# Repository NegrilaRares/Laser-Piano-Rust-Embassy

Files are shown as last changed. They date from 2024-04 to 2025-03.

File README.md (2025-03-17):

# Laser Piano
A piano made using laser diodes and laser receivers.

:::info 

**Author**: Negrila Rares \
**GitHub Project Link**: https://github.com/UPB-FILS-MA/project-NegrilaRares

:::

## Description

A piano made using laser diodes and laser receivers.

It uses a potentiometer with leds to adjust and show volume, 
3 separete switches with leds to displat change in octave 
and 7 laser diodes and laser receivers that act as the piano keys.

The plan is to take the sound data from an sd card and give it to a dac that will give the analog output to a audio jack module the is connected to a portable speaker.
It uses an LM386 audio amplifier module and 2 RC low pass filters to keep the signal clear and to a reasonable level.

## Motivation

The reason I chose this project is because I took an interest in laser diodes 
and wanted to learn file reading/writing from an external memory device 
as well as understand the conversion of digital code into analog sound.

## Architecture 

<!-- Add here the schematics with the architecture of your project. Make sure to include:
 - what are the main components (architecture components, not hardware components)
 - how they connect with each other
 -->

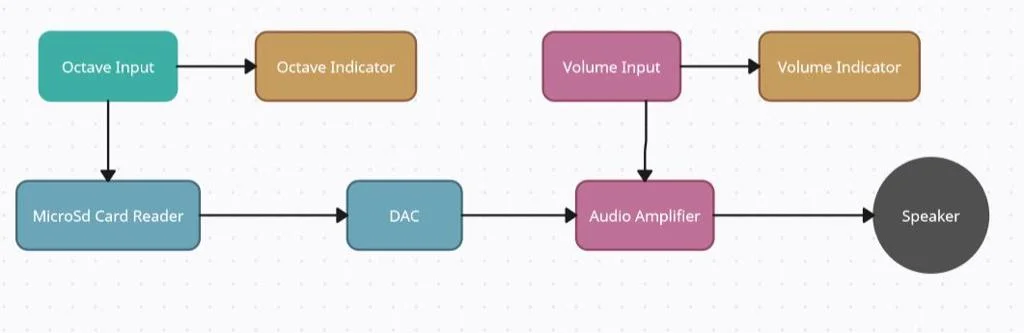
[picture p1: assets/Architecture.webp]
architecture
 

## Log

<!-- write every week your progress here -->

### Week 6 - 12 May

I encountered many problems with SD / microSD cards in embassy-rs.

While the setup initially used matched the Raspberry Pi Pico embedded-hal example from rp-rs using the embedded-sdmmc-rs crate, it did not behave as expected. The SD card itself failed to be read in any way, shape, or form. Even when manually sending CMD0, CMD1, and CMD8 commands, the response was not within the expected parameters.

In the end, I found a solution. I created a blocking::spi::SpiDevice using embassy_embedded_hal. 

For initialization, I had to give the program ownership over a phantom CS pin—a CS pin that could not be used and would no longer need to be used in the case of microSDs.

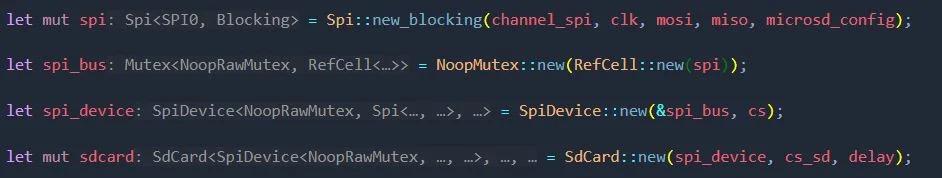
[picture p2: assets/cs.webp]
code_1


I opted for a normal SD card in the end, where I could still connect the second CS pin, given that the SD card module comes with 2 rows of pins.

### Week 7 - 19 May

After getting the SD card reader to work, I encountered my next challenge: data processing and the RAM limitations of the Raspberry Pi Pico.

Since the files themselves did not have too large of a PCM, storing them temporarily was not an issue. However, giving the data to the DAC proved to be a challenge.

For some reason, the while loop I was creating for processing did not accept any awaits or it would panic almost instantly. Additionally, giving the microcontroller too much to work on in too many iterations proved to be impossible.

To address this, I had to cut the files from 16-bit WAV files to 8-bit. This made processing much easier because now I only had to give an empty byte (with the first 4 bits setting the fast write mode of the DAC and the last 4 bits being empty data for the 12-bit interface) and the data bytes taken from the SD card. With this approach, I managed to cut the iterations from approximately 57,600 to about 28,650, and data processing to about 25%.

Despite these optimizations, the processing speed still proves to be insufficient. I see little solution to apply within my current limitations.

The biggest downside of using 8-bit files is that the sound quality took a significant plunge.

Now that I had my sound working, I needed to start working on clearing it up, as it was, at that time, an unintelligible mess.

To improve the sound quality, I switched to a portable speaker rather than the one I used before, and I attached an audio jack module to connect it. This proved to be insufficient, so I employed some RC low-pass filters to make some final touches.

While now there is still some static, it is nowhere near as bad as before. 
Despite the 8-bit sound quality, the sound can now be differentiated between keys.

### Week 20 - 26 May

The project ended up working perfectly on the breadboards as a prototype.

Sadly after putting the final version together, soldering everything on some prototype pcbs and putting everything in a wooden casing, I have lost a lot of the sound quality due to interference from the solder of the pcb.

Everything still functions ok.

The sound leaves a bit more to be desired when compared to the breadboard version.

This has been a lesson to me about analog waves and soldering, without experience, they don't go well together.

## Hardware

Using LEDs as settings indicators, buttons and a stereo potentiometer for octave and volume respectively.

Seven laser diodes are placed at an angle to continuously shine on the laser receivers.

An SD card reader is used with a 16GB SD card (the card has to use the W95 FAT32 (LBA) format). 

A DAC is used for processing the data and an amplifier is used to keep the signal at a desirable level.

Two RC low-pass filters are employed, each with 1780 kΩ resistors.

One filter uses a 0.1 µF capacitor, while the other uses a 0.22 µF capacitor.

The amplifier is connected to the opposite port of the stereo potentiometer, and the speaker is connected to the output of the amplifier through an audio jack module.

Full breadboard prototype:

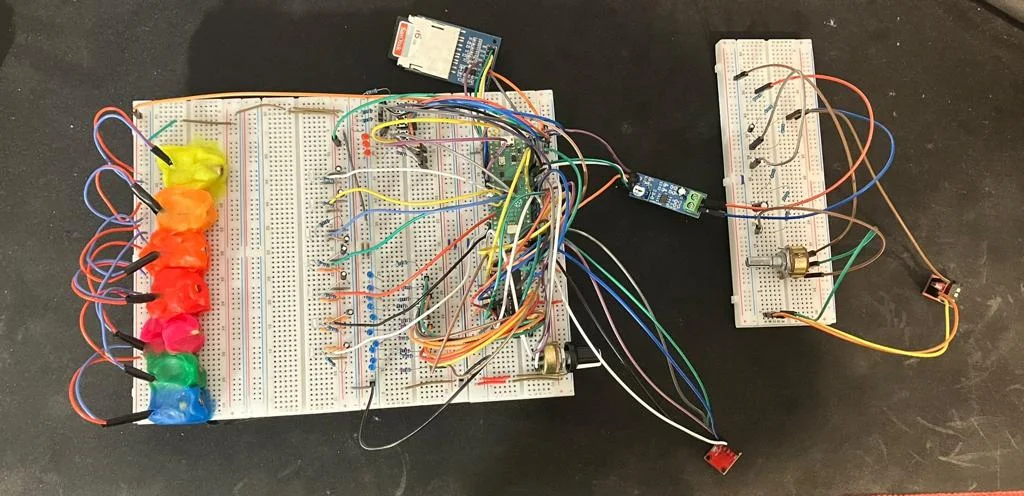
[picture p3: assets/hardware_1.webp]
hardware_on_breadboard


Laser processing:

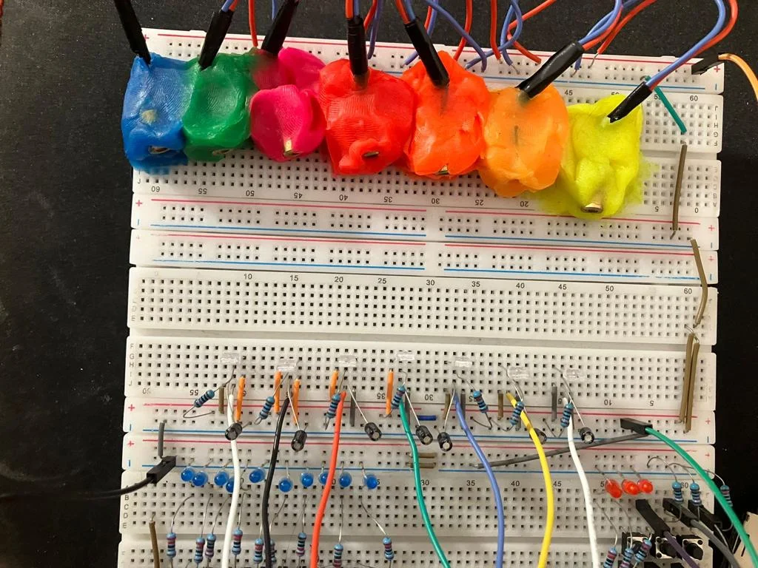
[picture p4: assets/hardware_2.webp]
hardware_on_breadboard


Analog signal processing:

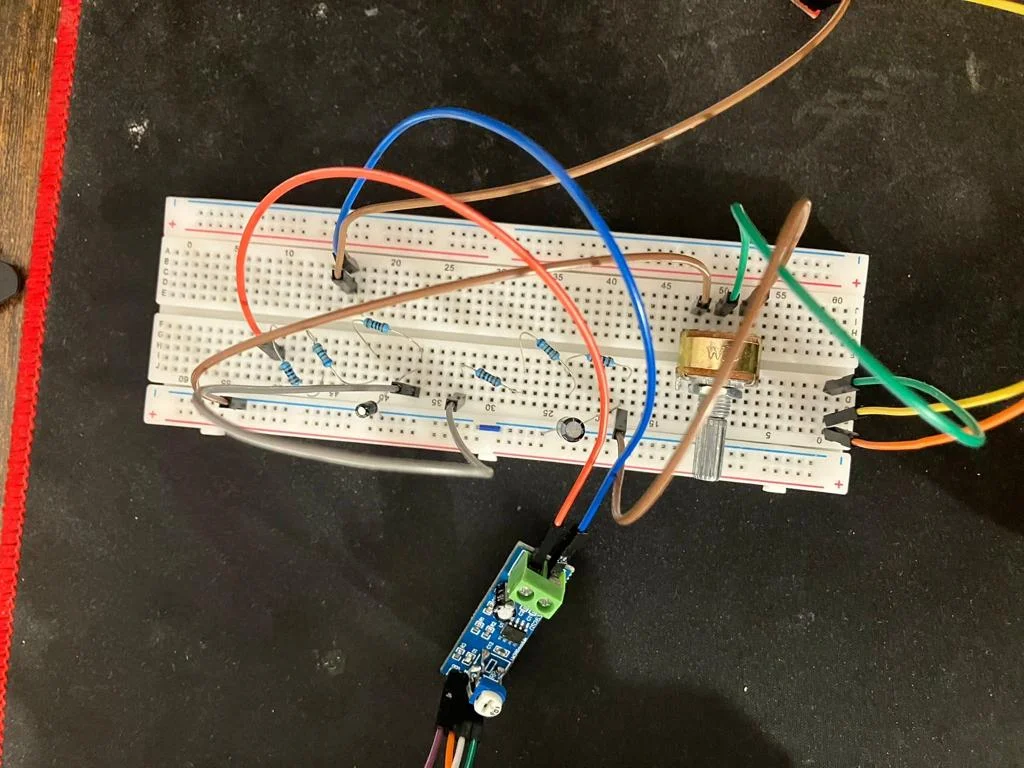
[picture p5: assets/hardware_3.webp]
hardware_on_breadboard


### Schematics

Some of the parts were either created by me as they did not have a publicly available schematic but most of the more detailed schemas for the modules used can be found in their datasheet.

In this case I couldn't find the Laser Receiver Symbol, the SD card reader module, the LM386 module and the audio jack module with the portable speaker. 

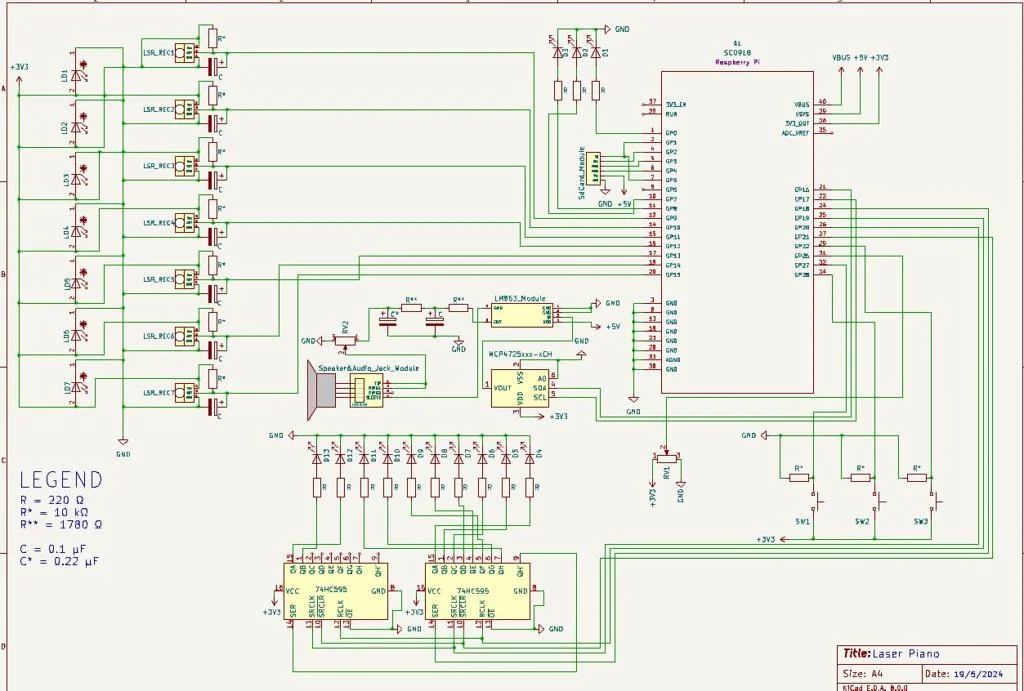
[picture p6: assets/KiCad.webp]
schematics


### Bill of Materials

<!-- Fill out this table with all the hardware components that you might need.

The format is 
```
| [Device](link://to/device) | This is used ... | [price](link://to/store) |

```

-->

| Device | Usage | Price |
|---|---|---|
| [Rapspberry Pi Pico W](https://www.raspberrypi.com/documentation/microcontrollers/raspberry-pi-pico.html) | The microcontroller | [35 RON](https://www.optimusdigital.ro/en/raspberry-pi-boards/12394-raspberry-pi-pico-w.html) |
| 13 * Led | This is used for displaying current settings | [-] |
| 13 * 220 Ohm R | This is used to make sure the leds don't get fried | [-] |
| 10 * 10 kOhm R | This is used to crate pull up and pull down resistors | [-] |
| 3 * 1780 Ohm R | This is used for the RC low pass filters | [-] |
| 7 * 0.1 uF Capacitor | This is used to debounce the signal from the laser receivers and for one of the low pass filters | [-] |
| 1 * 0.22 uF Capacitor | This is used for one of the low pass filters | [-] |
| lots * cables | This is used to connect diffrent things on the breadboard/prototype pcb | [-] |
| 10k Stereo Potentiometer | This is used for volume input | [2 RON](https://www.optimusdigital.ro/en/potentiometers/1886-10k-stereo-potentiometer.html) |
| 2 * [Shift Register](https://www.diodes.com/assets/Datasheets/74HC595.pdf) | This is used for the output of the volume setting | [2 RON](https://www.optimusdigital.ro/en/others/2448-registru-de-deplasare-74hc595-dip-16.html) |
| Laser Diode | This is used to generate a laser | [2.5 RON](https://ardushop.ro/ro/electronica/262-modul-dioda-laser-rou-5mw.html) |
| 7 * [ISO203](https://forum.arduino.cc/t/documents-about-laser-sensor-ds18b20/1090450/5) | This is used to monitor for interference in the path of the laser | [6.5 RON](https://www.optimusdigital.ro/en/others/3289-laser-diode-receiver.html) |
| SD card reader module | This is used to read the data from an SD card | [6 RON](https://www.optimusdigital.ro/en/others/98-sd-card-reader.html?search_query=sd+card&results=530) |
| [DAC MCP4725](https://ww1.microchip.com/downloads/en/devicedoc/22039d.pdf) | This is used to transfrom the binary from the audio file data into an analog singal for the speaker | [25 RON](https://www.optimusdigital.ro/en/others/1327-dac-mcp4725-module-with-i2c-interface.html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) |
| Portable Speaker | This is used to receive the analog signal through an audio jack module and create an appropriate sound | [-] |
| [AMP LM386](https://www.ti.com/lit/ds/symlink/lm386.pdf) | This is used amplify the analog singal | [6.5 RON](https://ardushop.ro/ro/electronica/241-modul-amplificator-audio-lm386.html) |
| Audio Jack Module | This is used amplify the analog singal | [5 RON](https://www.optimusdigital.ro/en/connectors/752-modul-jack-audio-stereo-de-35-mm.html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) |

## Software

| Library | Description | Usage |
|---|---|---|
| [SD card Crate](https://github.com/rust-embedded-community/embedded-sdmmc-rs) | Crate for the SD card reader | Used for reading pcm from wav files |
| [MCP4725 Crate](https://github.com/vgasparyan/mcp4725-rs) | Crate for the MCP4725 DAC | Used to send the data received from the microsd card to the digital to analog converter |
| [Framework used in project](https://github.com/embassy-rs/embassy)| Rust framework for embedded programming | Used to program the behaviour of the raspberry pi pico and used to simplify certain concepts of embedded programming |
| [Log](https://docs.rs/log/latest/log/)| Rust Crate for data displaying | Used to display data throught the usb in the terminal of the computer when interacting with the device as a manufacturer |
| [embassy-embedded-hal](https://docs.embassy.dev/embassy-embedded-hal/git/default/index.html)| Collection of utilities to use embedded-hal and embedded-storage traits with Embassy | Used to solve some sd card problems |
| [embassy-time](https://docs.rs/embassy-time/latest/embassy_time/)| Timekeeping, delays and timeouts. | Used to make time constraints and awaits. |
| [embassy-futures](https://docs.rs/embassy-futures/latest/embassy_futures/)| Utilities for working with futures, compatible with no_std and not using alloc. Optimized for code size, ideal for embedded systems. | Used to make await input actions. |

## Links

<!-- Add a few links that inspired you and that you think you will use for your project -->
1. [Laser Inspiration Video](https://youtu.be/h_y1y6eUvIY?si=NTLO8pDmCqerRG1a)
2. [Piano General Design Inspiration](https://www.amazon.com/M-WAVE-Controller-Bluetooth-Professional-Production/dp/B0B66T4DHK?th=1)

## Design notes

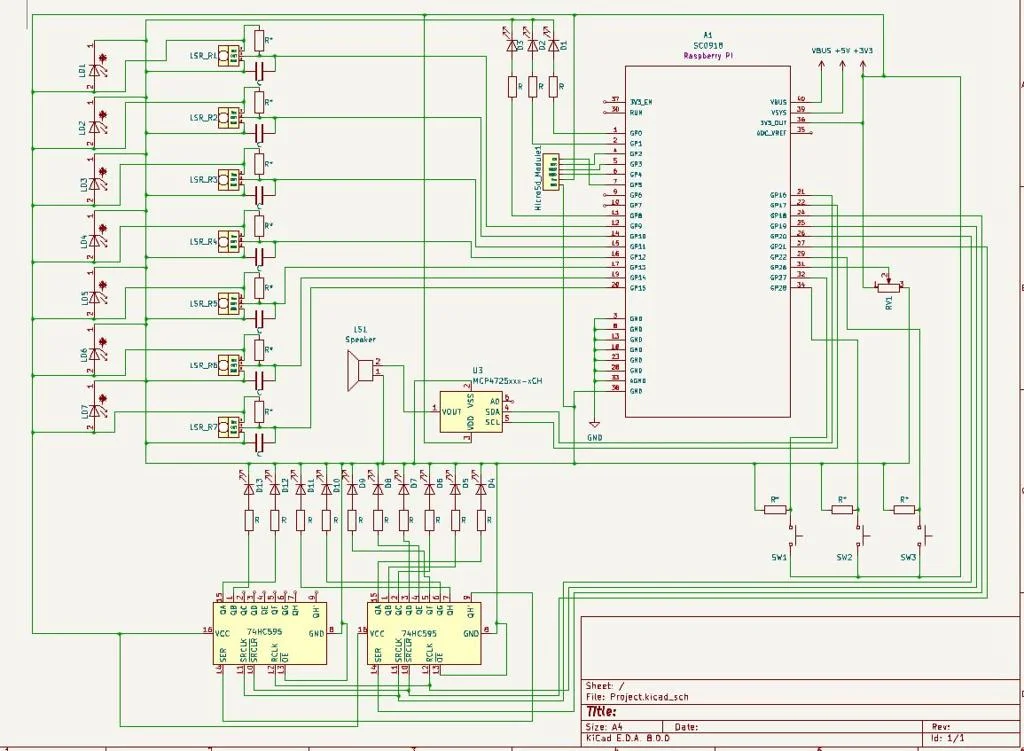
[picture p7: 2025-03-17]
assets/KiCad_before.webp

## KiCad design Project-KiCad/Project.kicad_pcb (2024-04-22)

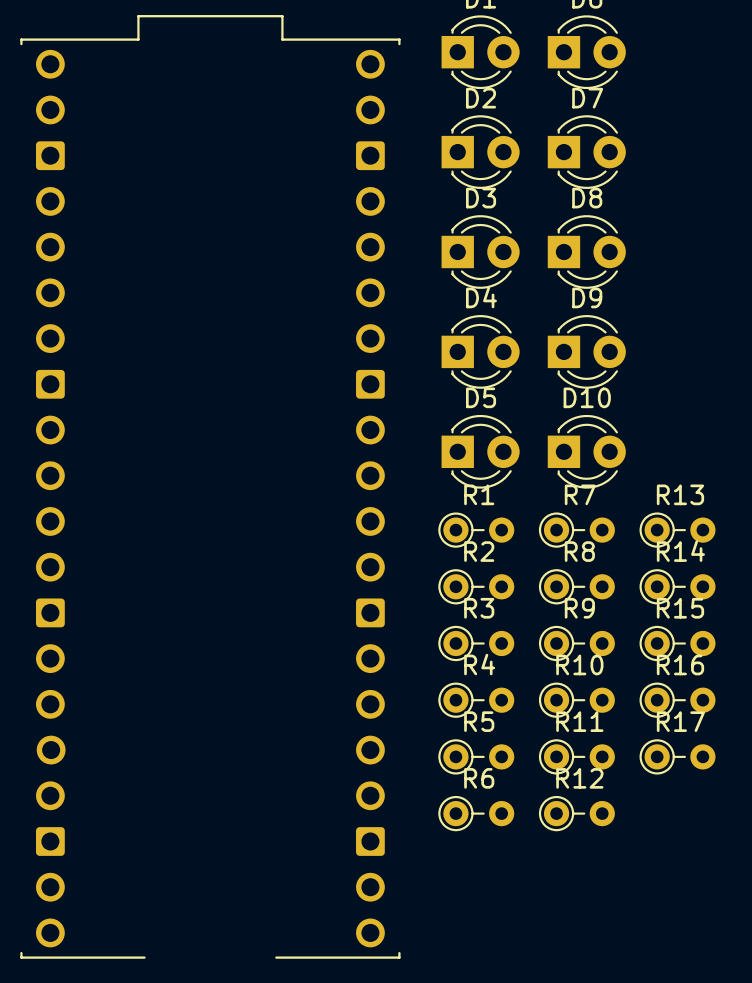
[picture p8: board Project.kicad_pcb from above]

Board: 2 copper layers, 28 parts (0 on the bottom side), 18 nets, no tracks yet.

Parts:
A1: SC0918; MODULE_SC0918
D1, D2, D3, D4, D5, D6, D7, D8, D9, D10: LED; LED_D3.0mm
R1, R2, R3, R4, R5, R6, R7, R8, R9, R10, R11, R12, R13, R14, R15, R16, R17: R; R_Axial_DIN0204_L3.6mm_D1.6mm_P2.54mm_Vertical

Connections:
unnamed: A1.1 (GP0), R11.2
unnamed: A1.2 (GP1), R12.2
unnamed: A1.4 (GP2), R13.2
unnamed: A1.5 (GP3), R14.2
unnamed: A1.6 (GP4), R15.2
unnamed: A1.7 (GP5), R16.2
unnamed: A1.9 (GP6), R17.2
unnamed: D1.2 (A), R1.2
unnamed: A1.38 (GND), D1.1 (K), D2.1 (K), D3.1 (K), D4.1 (K), D5.1 (K), D6.1 (K), D7.1 (K), D8.1 (K), D9.1 (K), D10.1 (K)
unnamed: D2.2 (A), R2.1
unnamed: D3.2 (A), R3.2
unnamed: D4.2 (A), R4.2
unnamed: D5.2 (A), R5.1
unnamed: D6.2 (A), R6.2
unnamed: D7.2 (A), R7.2
unnamed: D8.2 (A), R8.2
unnamed: D9.2 (A), R9.2
unnamed: D10.2 (A), R10.2

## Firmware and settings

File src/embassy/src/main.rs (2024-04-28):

#![no_std]
#![no_main]
#![allow(unused_imports, dead_code, unused_variables, unused_mut)] // i removed allowing dead_code as i did not know what that entailed


use core::cell::RefCell;
use core::panic::PanicInfo;
use embassy_executor::Spawner;

//SD
use embedded_sdmmc::{SdCard, TimeSource, Timestamp, VolumeIdx, VolumeManager};
use embedded_sdmmc::Volume;
use embedded_sdmmc::VolumeType::Fat;
use embedded_sdmmc::filesystem::Mode;
use embassy_rp::spi;
use embassy_rp::spi::Spi;
use embedded_hal::delay::DelayNs;


#[derive(Default)]
pub struct DummyTimesource();

impl TimeSource for DummyTimesource {
    fn get_timestamp(&self) -> Timestamp {
        Timestamp {
            year_since_1970: 0,
            zero_indexed_month: 0,
            zero_indexed_day: 0,
            hours: 0,
            minutes: 0,
            seconds: 0,
        }
    }
}

//GPIO
use embassy_rp::gpio::{
    AnyPin, 
    self, 
    Input, 
    Pull, 
    Pin,
    Level,
    Output, 
};

//Peripherals
use embassy_rp::peripherals::{
    ADC, DMA_CH0, DMA_CH1, PIN_0, PIN_1, PIN_10, PIN_11, PIN_12, PIN_13, PIN_14, PIN_15, PIN_16, PIN_17, PIN_18, PIN_19, PIN_2, PIN_20, PIN_21, PIN_22, PIN_23, PIN_24, PIN_25, PIN_26, PIN_27, PIN_28, PIN_3, PIN_4, PIN_5, PIN_6, PIN_7, PIN_8, PIN_9, SPI0, USB
};

// PWM
use embassy_rp::pwm::{
    Config as ConfigPWM, 
    Pwm,
};

use embassy_rp::adc::{
    Adc, 
    Async, 
    Channel as ChannelADC, 
    Config as ConfigADC, 
    InterruptHandler as InterruptHandlerADC,
};

// USB
use embassy_rp::usb::{
    Driver, 
    InterruptHandler,
};
use embassy_rp::bind_interrupts;
use log::{info, error};

// Channel
use embassy_sync::blocking_mutex::raw::ThreadModeRawMutex;
use embassy_sync::channel::{
    Channel, 
    Receiver, 
    Sender
};

// Timer
use embassy_time::{
    Delay, 
    Timer, 
    Duration,
};


// Select futures
use embassy_futures::select::select;
use embassy_futures::select::Either::{First as First1, Second as Second1};
use embassy_futures::select::Either3::{First as First3, Second as Second3, Third as Third3};
use embassy_futures::select::select3;

use embassy_futures::select::select_array;
use embassy_futures::select::SelectArray;

use core::future::Future;
use core::pin::Pin as corePin;
use core::task::{Context, Poll};

#[derive(Debug, Clone)]
#[cfg_attr(feature = "defmt", derive(defmt::Format))]
pub enum Either7<A, B, C, D, E, F, G> {
    First(A),
    Second(B),
    Third(C),
    Forth(D),
    Fifth(E),
    Sixth(F),
    Seventh(G)
}

pub fn select7<A, B, C, D, E, F, G>(a: A, b: B, c: C, d: D, e: E, f: F, g: G) -> Select7<A, B, C, D, E, F, G>
where
    A: Future,
    B: Future,
    C: Future,
    D: Future,
    E: Future,
    F: Future,
    G: Future,
{
    Select7 { a, b, c, d, e, f, g }
}


#[derive(Debug)]
#[must_use = "futures do nothing unless you `.await` or poll them"]
pub struct Select7<A, B, C, D, E, F, G> {
    a: A,
    b: B,
    c: C,
    d: D, 
    e: E, 
    f: F, 
    g: G,
}

impl<A, B, C, D, E, F, G> Future for Select7<A, B, C, D, E, F, G>
where
    A: Future,
    B: Future,
    C: Future,
    D: Future,
    E: Future,
    F: Future,
    G: Future,
{
    type Output = Either7<A::Output, B::Output, C::Output, D::Output, E::Output, F::Output, G::Output>;

    fn poll(self: corePin<&mut Self>, cx: &mut Context<'_>) -> Poll<Self::Output> {
        let this = unsafe { self.get_unchecked_mut() };
        let a = unsafe { corePin::new_unchecked(&mut this.a) };
        let b = unsafe { corePin::new_unchecked(&mut this.b) };
        let c = unsafe { corePin::new_unchecked(&mut this.c) };
        let d = unsafe { corePin::new_unchecked(&mut this.d) };
        let e = unsafe { corePin::new_unchecked(&mut this.e) };
        let f = unsafe { corePin::new_unchecked(&mut this.f) };
        let g = unsafe { corePin::new_unchecked(&mut this.g) };
        if let Poll::Ready(x) = a.poll(cx) {
            return Poll::Ready(Either7::First(x));
        }
        if let Poll::Ready(x) = b.poll(cx) {
            return Poll::Ready(Either7::Second(x));
        }
        if let Poll::Ready(x) = c.poll(cx) {
            return Poll::Ready(Either7::Third(x));
        }
        if let Poll::Ready(x) = d.poll(cx) {
            return Poll::Ready(Either7::Forth(x));
        }
        if let Poll::Ready(x) = e.poll(cx) {
            return Poll::Ready(Either7::Fifth(x));
        }
        if let Poll::Ready(x) = f.poll(cx) {
            return Poll::Ready(Either7::Sixth(x));
        }
        if let Poll::Ready(x) = g.poll(cx) {
            return Poll::Ready(Either7::Seventh(x));
        }
        Poll::Pending
    }
}

#[embassy_executor::task]
async fn logger_task(driver: Driver<'static, USB>) {
    embassy_usb_logger::run!(1024, log::LevelFilter::Info, driver);
}

const DISPLAY_FREQ: u32 = 64_000_000;bind_interrupts!(struct Irqs {
    USBCTRL_IRQ => InterruptHandler<USB>;
    ADC_IRQ_FIFO => InterruptHandlerADC;
});

pub enum VolLvl{
    ONE,
    TWO,
    THREE,
    FOUR,
    FIVE, 
    SIX,
    SEVEN,
    EIGHT,
    NINE,
    TEN,
}

pub enum OctLvl{
    ONE,
    TWO,
    THREE,
}

pub enum LsrLvl{
    ONE,
    TWO,
    THREE,
    FOUR,
    FIVE,
    SIX,
    SEVEN,
}

static VOLUME_CHANNEL: Channel<ThreadModeRawMutex, VolLvl, 64> = Channel::new();
static OCTAVE_CHANNEL: Channel<ThreadModeRawMutex, OctLvl, 64> = Channel::new();
static LASER_CHANNEL: Channel<ThreadModeRawMutex, LsrLvl, 64> = Channel::new();

#[embassy_executor::task]
async fn oct_input(
    channel_sender_octave: Sender<'static, ThreadModeRawMutex, OctLvl, 64>,
    mut sw_1:Input<'static, PIN_27>,
    mut sw_2:Input<'static, PIN_28>,
    mut sw_3:Input<'static, PIN_22>,
){
    loop{
        let select = select3(sw_1.wait_for_rising_edge(), sw_2.wait_for_rising_edge(), sw_3.wait_for_rising_edge()).await;

        match select {
            First3(switch_1) => {
                channel_sender_octave.send(OctLvl::ONE).await;
            }
            Second3(switch_2) => {
                channel_sender_octave.send(OctLvl::TWO).await;
            }
            Third3(switch_3) => {
                channel_sender_octave.send(OctLvl::THREE).await;
            }
        }
    }
}

#[embassy_executor::task]
async fn vol_input(
    mut potentiometer: ChannelADC<'static>, 
    mut adc: Adc<'static, Async>, 
    channel_sender_volume: Sender<'static, ThreadModeRawMutex, VolLvl, 64>,
    mut clk:Output<'static, PIN_20>,
    mut data:Output<'static, PIN_18>,
    mut latch:Output<'static, PIN_19>,
    mut reset:Output<'static, PIN_21>,
) {
    loop{
        //info!("Waiting!");
        let value = adc.read(&mut potentiometer).await.unwrap(); // (19)20(21) - 4095  
        //info!("Result: {:?}", value);
        match value {
            0..=426 => {
                info!("Value is in range 1: <0, 426>");
                channel_sender_volume.send(VolLvl::ONE).await;
                let mut max = 1;
                let mut i = 0;
                reset.set_low();
                Timer::after_nanos(100).await;
                reset.set_high();
                Timer::after_nanos(100).await;
                while i < max
                {
                    data.set_high();
                    clk.set_high();
                    Timer::after_nanos(100).await;
                    clk.set_low();
                    data.set_low();
                    Timer::after_nanos(100).await;
                    i = i + 1;
                }
                latch.set_high();
                Timer::after_nanos(100).await;
                latch.set_low();
                Timer::after_nanos(100).await;
            } ,
            427..=833 => {
                info!("Value is in range 2: <427, 833>");
                channel_sender_volume.send(VolLvl::TWO).await;
                let mut max = 2;
                let mut i = 0;
                reset.set_low();
                Timer::after_nanos(100).await;
                reset.set_high();
                Timer::after_nanos(100).await;
                while i < max
                {
                    data.set_high();
                    clk.set_high();
                    Timer::after_nanos(100).await;
                    clk.set_low();
                    data.set_low();
                    Timer::after_nanos(100).await;
                    i = i + 1;
                }
                latch.set_high();
                Timer::after_nanos(100).await;
                latch.set_low();
                Timer::after_nanos(100).await;
            },
            834..=1240 => {
                info!("Value is in range 3: <834, 1240>");
                channel_sender_volume.send(VolLvl::THREE).await;
                let mut max = 3;
                let mut i = 0;
                reset.set_low();
                Timer::after_nanos(100).await;
                reset.set_high();
                Timer::after_nanos(100).await;
                while i < max
                {
                    data.set_high();
                    clk.set_high();
                    Timer::after_nanos(100).await;
                    clk.set_low();
                    data.set_low();
                    Timer::after_nanos(100).await;
                    i = i + 1;
                }
                latch.set_high();
                Timer::after_nanos(100).await;
                latch.set_low();
                Timer::after_nanos(100).await;
            },
            1241..=1647 => {
                info!("Value is in range 4: <1241, 1647>");
                channel_sender_volume.send(VolLvl::FOUR).await;
                let mut max = 4;
                let mut i = 0;
                reset.set_low();
                Timer::after_nanos(100).await;
                reset.set_high();
                Timer::after_nanos(100).await;
                while i < max
                {
                    data.set_high();
                    clk.set_high();
                    Timer::after_nanos(100).await;
                    clk.set_low();
                    data.set_low();
                    Timer::after_nanos(100).await;
                    i = i + 1;
                }
                latch.set_high();
                Timer::after_nanos(100).await;
                latch.set_low();
                Timer::after_nanos(100).await;
            },
            1648..=2054 => {
                info!("Value is in range 5: <1648, 2054>");
                channel_sender_volume.send(VolLvl::FIVE).await;
                let mut max = 5;
                let mut i = 0;
                reset.set_low();
                Timer::after_nanos(100).await;
                reset.set_high();
                Timer::after_nanos(100).await;
                while i < max
                {
                    data.set_high();
                    clk.set_high();
                    Timer::after_nanos(100).await;
                    clk.set_low();
                    data.set_low();
                    Timer::after_nanos(100).await;
                    i = i + 1;
                }
                latch.set_high();
                Timer::after_nanos(100).await;
                latch.set_low();
                Timer::after_nanos(100).await;
            },
            2055..=2461 => {
                info!("Value is in range 6: <2055, 2461>");
                channel_sender_volume.send(VolLvl::SIX).await;
                let mut max = 6;
                let mut i = 0;
                reset.set_low();
                Timer::after_nanos(100).await;
                reset.set_high();
                Timer::after_nanos(100).await;
                while i < max
                {
                    data.set_high();
                    clk.set_high();
                    Timer::after_nanos(100).await;
                    clk.set_low();
                    data.set_low();
                    Timer::after_nanos(100).await;
                    i = i + 1;
                }
                latch.set_high();
                Timer::after_nanos(100).await;
                latch.set_low();
                Timer::after_nanos(100).await;
            },
            2462..=2868 => {
                info!("Value is in range 7: <2462, 2868>");
                channel_sender_volume.send(VolLvl::SEVEN).await;
                let mut max = 7;
                let mut i = 0;
                reset.set_low();
                Timer::after_nanos(100).await;
                reset.set_high();
                Timer::after_nanos(100).await;
                while i < max
                {
                    data.set_high();
                    clk.set_high();
                    Timer::after_nanos(100).await;
                    clk.set_low();
                    data.set_low();
                    Timer::after_nanos(100).await;
                    i = i + 1;
                }
                latch.set_high();
                Timer::after_nanos(100).await;
                latch.set_low();
                Timer::after_nanos(100).await;
            },
            2869..=3275 => {
                info!("Value is in range 8: <2869, 3275>");
                channel_sender_volume.send(VolLvl::EIGHT).await;
                let mut max = 8;
                let mut i = 0;
                reset.set_low();
                Timer::after_nanos(100).await;
                reset.set_high();
                Timer::after_nanos(100).await;
                while i < max
                {
                    data.set_high();
                    clk.set_high();
                    Timer::after_nanos(100).await;
                    clk.set_low();
                    data.set_low();
                    Timer::after_nanos(100).await;
                    i = i + 1;
                }
                latch.set_high();
                Timer::after_nanos(100).await;
                latch.set_low();
                Timer::after_nanos(100).await;
            },
            3276..=3682 => {
                info!("Value is in range 9: <3276, 3682>");
                channel_sender_volume.send(VolLvl::NINE).await;
                let mut max = 9;
                let mut i = 0;
                reset.set_low();
                Timer::after_nanos(100).await;
                reset.set_high();
                Timer::after_nanos(100).await;
                while i < max
                {
                    data.set_high();
                    clk.set_high();
                    Timer::after_nanos(100).await;
                    clk.set_low();
                    data.set_low();
                    Timer::after_nanos(100).await;
                    i = i + 1;
                }
                latch.set_high();
                Timer::after_nanos(100).await;
                latch.set_low();
                Timer::after_nanos(100).await;
            },
            3683..=4095 => {
                info!("Value is in range 10: <3683, 4095>");
                channel_sender_volume.send(VolLvl::TEN).await;
                let mut max = 10;
                let mut i = 0;
                reset.set_low();
                Timer::after_nanos(100).await;
                reset.set_high();
                Timer::after_nanos(100).await;
                while i < max
                {
                    data.set_high();
                    clk.set_high();
                    Timer::after_nanos(100).await;
                    clk.set_low();
                    data.set_low();
                    Timer::after_nanos(100).await;
                    i = i + 1;
                }
                latch.set_high();
                Timer::after_nanos(100).await;
                latch.set_low();
                Timer::after_nanos(100).await;
            },
            _ => info!("Value is not in any defined range"),
        }
        Timer::after_millis(100).await;
    }
}
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
async fn main(spawner: Spawner) {
	let p = embassy_rp::init(Default::default());

    let driver = Driver::new(p.USB, Irqs);
    spawner.spawn(logger_task(driver)).unwrap();

    let mut adc = Adc::new(p.ADC, Irqs, ConfigADC::default());
    let mut potentiometer = ChannelADC::new_pin(p.PIN_26, Pull::None);

    let mut clock = Output::new(p.PIN_20, Level::Low);
    let mut in_data = Output::new(p.PIN_18, Level::Low);
    let mut latch = Output::new(p.PIN_19, Level::Low);
    let mut clear = Output::new(p.PIN_21, Level::High);

    let mut oct_1_led = Output::new(p.PIN_0, Level::Low);
    let mut oct_2_led = Output::new(p.PIN_1, Level::Low);
    let mut oct_3_led = Output::new(p.PIN_8, Level::Low);

    let mut sw_oct_1 = Input::new(p.PIN_27, Pull::Down);
    let mut sw_oct_2 = Input::new(p.PIN_28, Pull::Down);
    let mut sw_oct_3 = Input::new(p.PIN_22, Pull::Down);

    let mut input_1 = Input::new(p.PIN_9, Pull::Up);
    let mut input_2 = Input::new(p.PIN_10, Pull::Up);
    let mut input_3 = Input::new(p.PIN_11, Pull::Up);
    let mut input_4 = Input::new(p.PIN_12, Pull::Up);
    let mut input_5 = Input::new(p.PIN_13, Pull::Up);
    let mut input_6 = Input::new(p.PIN_14, Pull::Up);
    let mut input_7 = Input::new(p.PIN_15, Pull::Up);

    let miso = p.PIN_4;
    let mosi = p.PIN_3;
    let clk = p.PIN_2;

    let mut microsd_cs = Output::new(p.PIN_5, Level::High);
    let mut spi_channel = p.SPI0;
    let mut dma_spi_1 = p.DMA_CH0;
    let mut dma_spi_2 = p.DMA_CH1;

    // let _ =spawner.spawn(
    //     vol_input(
    //         potentiometer, 
    //         adc, 
    //         VOLUME_CHANNEL.sender(), 
    //         clock, 
    //         in_data, 
    //         latch,
    //         clear,
    //     )
    // ).unwrap();

    // let _ =spawner.spawn(
    //     oct_input(
    //         OCTAVE_CHANNEL.sender(),
    //         sw_oct_1, 
    //         sw_oct_2, 
    //         sw_oct_3
    //     )
    // );

    // let _ =spawner.spawn(
    //     lsr_input(
    //         LASER_CHANNEL.sender(),
    //         input_1, 
    //         input_2,
    //         input_3,
    //         input_4,
    //         input_5,
    //         input_6,
    //         input_7,
    //     )
    // );
    
    let _ =spawner.spawn(
        sd_card(
            miso,
            mosi,
            clk,
            microsd_cs,
            spi_channel,
            dma_spi_1,
            dma_spi_2,
        )
    );
    
    
    let mut volume: VolLvl = VolLvl::ONE;
    let mut octave: OctLvl = OctLvl::TWO;
    oct_1_led.set_low();
    oct_2_led.set_high();
    oct_3_led.set_low();
    let mut lsr: LsrLvl = LsrLvl::ONE;
    let mut var = 0;

    loop {
        let select = select3(VOLUME_CHANNEL.receive(), OCTAVE_CHANNEL.receive(),LASER_CHANNEL.receive()).await;

        match select {
            First3(volume_value) =>{
                match volume_value{
                    VolLvl::ONE => {

                    }
                    VolLvl::TWO => {

                    }
                    VolLvl::THREE => {

                    }
                    VolLvl::FOUR => {

                    }
                    VolLvl::FIVE => {

                    }
                    VolLvl::SIX => {

                    }
                    VolLvl::SEVEN => {

                    }
                    VolLvl::EIGHT => {

                    }
                    VolLvl::NINE => {

                    }
                    VolLvl::TEN => {

                    }
                }                
            }
            Second3(octave_value) =>{
                match octave_value{
                    OctLvl::ONE => {
                        oct_1_led.set_high();
                        oct_2_led.set_low();
                        oct_3_led.set_low();
                    }
                    OctLvl::TWO => {
                        oct_1_led.set_low();
                        oct_2_led.set_high();
                        oct_3_led.set_low();
                    }
                    OctLvl::THREE => {
                        oct_1_led.set_low();
                        oct_2_led.set_low();
                        oct_3_led.set_high();
                    }
                }
            }
            Third3(lsr_value) =>{
                match lsr_value{
                    LsrLvl::ONE =>{
                        info!("{} ONE!",var);
                        var += 1;
                    }
                    LsrLvl::TWO =>{
                        info!("{} TWO!",var);
                        var += 1;
                    }
                    LsrLvl::THREE =>{
                        info!("{} THREE!",var);
                        var += 1;
                    }
                    LsrLvl::FOUR =>{
                        info!("{} FOUR!",var);
                        var += 1;
                    }
                    LsrLvl::FIVE =>{
                        info!("{} FIVE!",var);
                        var += 1;
                    }
                    LsrLvl::SIX =>{
                        info!("{} SIX!",var);
                        var += 1;
                    }
                    LsrLvl::SEVEN =>{
                        info!("{} SEVEN!",var);
                        var += 1;
                    }
                }
            }
        }



    }
}

#[panic_handler]
fn panic(_info: &PanicInfo) -> ! {
    loop {}
}

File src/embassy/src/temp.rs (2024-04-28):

//! # Pico SD Card Example
//!
//! Reads and writes a file from/to the SD Card that is formatted in FAT32.
//! This example uses the SPI0 device of the Raspberry Pi Pico on the
//! pins 4,5,6 and 7. If you don't use an external 3.3V power source,
//! you can connect the +3.3V output on pin 36 to the SD card.
//!
//! SD Cards up to 2TB are supported by the `embedded_sdmmc` crate.
//! I've tested this with a 64GB micro SD card.
//!
//! You need to format the card with an regular old FAT32 filesystem
//! and also make sure the first partition has the right type. This is how your
//! `fdisk` output should look like:
//!
//! ```text
//!     fdisk /dev/sdj
//!
//!     Welcome to fdisk (util-linux 2.34).
//!     Changes will remain in memory only, until you decide to write them.
//!     Be careful before using the write command.
//!
//!     Command (m for help): Disk /dev/sdj:
//!     59,49 GiB, 63864569856 bytes, 124735488 sectors
//!     Disk model: SD/MMC/MS/MSPRO
//!     Units: sectors of 1 * 512 = 512 bytes
//!     Sector size (logical/physical): 512 bytes / 512 bytes
//!     I/O size (minimum/optimal): 512 bytes / 512 bytes
//!     Disklabel type: dos
//!     Disk identifier: 0x00000000
//!
//!     Device     Boot Start       End   Sectors  Size Id Type
//!     /dev/sdj1        2048 124735487 124733440 59,5G  c W95 FAT32 (LBA)
//! ```
//!
//! The important bit here is the _Type_ with `W95 FAT32 (LBA)`, other types
//! are rejected by the `embedded_sdmmc` filesystem implementation.
//!
//! Formatting the partition can be done using `mkfs.fat`:
//!
//!     $ mkfs.fat /dev/sdj1
//!
//! The example can either be used with a probe to receive debug output
//! and also the LED is used as status output. There are different blinking
//! patterns.
//!
//! For every successful stage in the example the LED will blink long once.
//! If everything is successful (9 long blink signals), the example will go
//! into a loop and either blink in a _"short long"_ or _"short short long"_ pattern.
//!
//! If there are 4 different error patterns, all with short blinking pulses:
//!
//! - **3 short blink (in a loop)**: Card size could not be retrieved.
//! - **4 short blink (in a loop)**: Error getting volume/partition 0.
//! - **5 short blink (in a loop)**: Error opening root directory.
//! - **6 short blink (in a loop)**: Could not open file 'O.TST'.
//!
//! See the `Cargo.toml` file for Copyright and license details.

#![no_std]
#![no_main]

// The macro for our start-up function
use rp_pico::entry;

// info!() and error!() macros for printing information to the debug output
use defmt::*;
use defmt_rtt as _;

// Ensure we halt the program on panic (if we don't mention this crate it won't
// be linked)
use panic_halt as _;

// Pull in any important traits
use rp_pico::hal::prelude::*;

// Embed the `Hz` function/trait:
use fugit::RateExtU32;

// A shorter alias for the Peripheral Access Crate, which provides low-level
// register access
use rp_pico::hal::pac;

// Import the SPI abstraction:
use rp_pico::hal::spi;

// Import the GPIO abstraction:
use rp_pico::hal::gpio;

// A shorter alias for the Hardware Abstraction Layer, which provides
// higher-level drivers.
use rp_pico::hal;

// Link in the embedded_sdmmc crate.
// The `SdMmcSpi` is used for block level access to the card.
// And the `VolumeManager` gives access to the FAT filesystem functions.
use embedded_sdmmc::{SdCard, TimeSource, Timestamp, VolumeIdx, VolumeManager};

// Get the file open mode enum:
use embedded_sdmmc::filesystem::Mode;

use embedded_hal::delay::DelayNs;
use rp2040_hal::Timer;

/// A dummy timesource, which is mostly important for creating files.
#[derive(Default)]
pub struct DummyTimesource();

impl TimeSource for DummyTimesource {
    // In theory you could use the RTC of the rp2040 here, if you had
    // any external time synchronizing device.
    fn get_timestamp(&self) -> Timestamp {
        Timestamp {
            year_since_1970: 0,
            zero_indexed_month: 0,
            zero_indexed_day: 0,
            hours: 0,
            minutes: 0,
            seconds: 0,
        }
    }
}

// Setup some blinking codes:
const BLINK_OK_LONG: [u8; 1] = [8u8];
const BLINK_OK_SHORT_LONG: [u8; 4] = [1u8, 0u8, 6u8, 0u8];
const BLINK_OK_SHORT_SHORT_LONG: [u8; 6] = [1u8, 0u8, 1u8, 0u8, 6u8, 0u8];
const BLINK_ERR_3_SHORT: [u8; 6] = [1u8, 0u8, 1u8, 0u8, 1u8, 0u8];
const BLINK_ERR_4_SHORT: [u8; 8] = [1u8, 0u8, 1u8, 0u8, 1u8, 0u8, 1u8, 0u8];
const BLINK_ERR_5_SHORT: [u8; 10] = [1u8, 0u8, 1u8, 0u8, 1u8, 0u8, 1u8, 0u8, 1u8, 0u8];
const BLINK_ERR_6_SHORT: [u8; 12] = [1u8, 0u8, 1u8, 0u8, 1u8, 0u8, 1u8, 0u8, 1u8, 0u8, 1u8, 0u8];

fn blink_signals(
    pin: &mut dyn embedded_hal::digital::OutputPin<Error = core::convert::Infallible>,
    delay: &mut dyn DelayNs,
    sig: &[u8],
) {
    for bit in sig {
        if *bit != 0 {
            pin.set_high().unwrap();
        } else {
            pin.set_low().unwrap();
        }

        let length = if *bit > 0 { *bit } else { 1 };

        for _ in 0..length {
            delay.delay_ms(100);
        }
    }

    pin.set_low().unwrap();

    delay.delay_ms(500);
}

fn blink_signals_loop(
    pin: &mut dyn embedded_hal::digital::OutputPin<Error = core::convert::Infallible>,
    delay: &mut dyn DelayNs,
    sig: &[u8],
) -> ! {
    loop {
        blink_signals(pin, delay, sig);
        delay.delay_ms(1000);
    }
}
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
